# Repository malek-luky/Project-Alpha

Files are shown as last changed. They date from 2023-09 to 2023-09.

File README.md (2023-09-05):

# Project Alpha - THRUST VECTOR CONTROLLED ROCKET MODEL
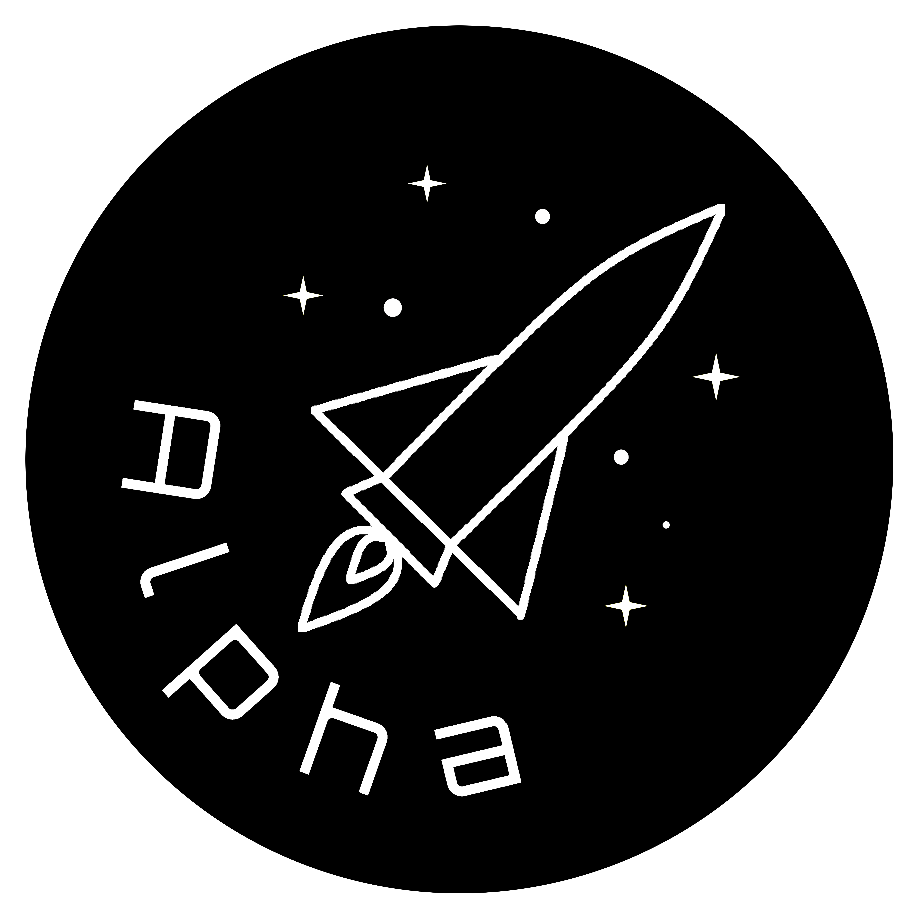
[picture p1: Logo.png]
Project Alpha Logo


## Table of Contents
- [Introduction](#introduction)
- [Material](#material)
- [3D Model](#3d-model)
- [Flight Software](#flight-software)
- [Disclaimer](#disclaimer)

## Introduction
Welcome to the repository for Project Alpha, a bachelor thesis project conducted at the Czech Technical University in Prague. This project focuses on the development and implementation of a thrust vector controlled rocket model. This README.md provides an overview of the project, its materials, and a brief disclaimer regarding the use of the flight software.

## Material
### Flight Computer
- **Barometer**: BMP388
- **Orientation Sensor**: BNO055
- **Microcontroller**: Teensy 4.1

### Additional Hardware
- **Servo Motor**: SG92R
- **Rocket Motor**: Klima D3-P

## 3D Model
The 3D model files included in this repository are essential for printing the rocket. These files come in both STL and Autodesk Inventor formats, providing flexibility for users. The rocket model was specifically designed to accommodate a custom PCB and has been printed using ASA material.

## Flight Software
**Important:** The flight software provided in this repository is experimental and should be used at your own risk. It is intended to serve as a reference and a starting point for your own projects or research related to thrust vector controlled rocketry. Make sure to thoroughly test and validate any modifications you make to the software before using it for an actual rocket launch.

The flight software includes code for controlling the rocket's flight based on data from the sensors and the servo motor. It is designed to assist in achieving thrust vector control, a critical aspect of rocket stability during flight.

## Disclaimer
Launching the rocket based on the mentioned steps and utilizing the flight software is entirely at your own risk. This repository is meant to provide inspiration and study material for educational purposes and research. It is not intended as a comprehensive guide or a guarantee of a fully working prototype.

Safety is paramount when dealing with rocketry, and it is essential to adhere to all safety regulations and guidelines established by your local authorities. Always conduct thorough testing and follow best practices to ensure the safety of yourself and others involved in the project.

If you have any questions or need further information about Project Alpha, feel free to reach out to the project contributors listed in the repository. Good luck with your research and exploration in the field of thrust vector controlled rocketry!

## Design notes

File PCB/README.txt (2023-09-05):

How to use：
1) Open EesyEDA
2) Create new Project
3) Import schematics json (Top menu - File - Open - EasyEDA)
4) Import PCB json

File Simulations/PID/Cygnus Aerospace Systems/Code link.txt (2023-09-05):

https://codesandbox.io/s/rocket-sim-final-with-position-control-dual-motor-0oq6u

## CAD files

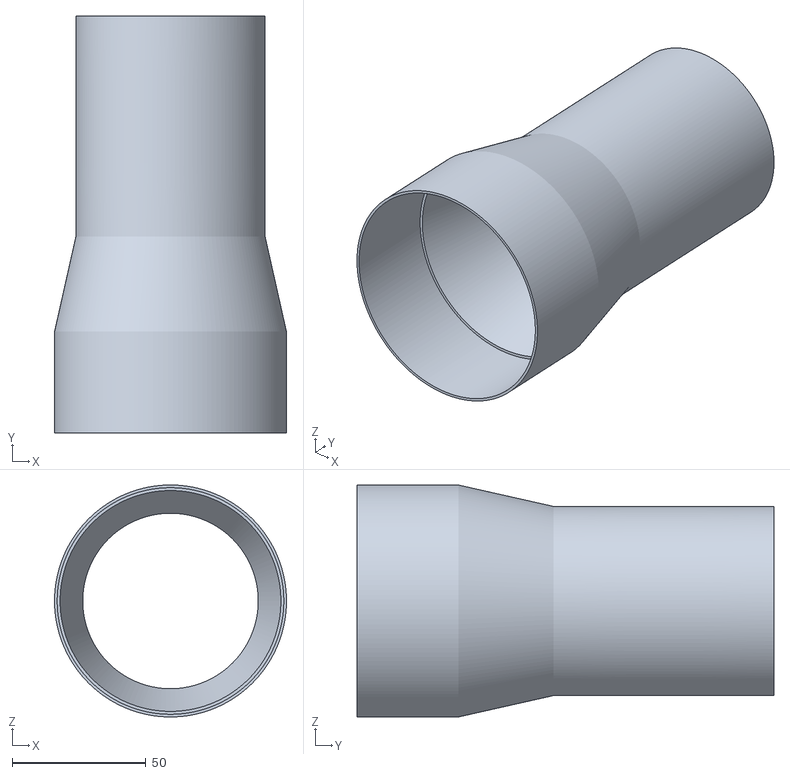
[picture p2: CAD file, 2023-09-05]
3D Models/BottomTubeUp_v7.stl
86.6 x 155.6 x 86.6

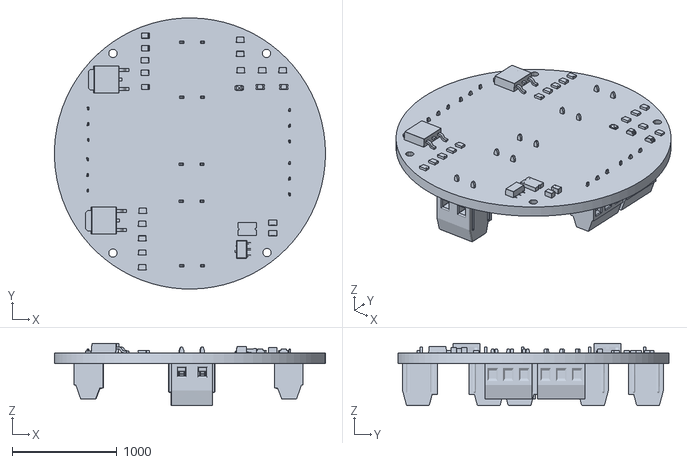
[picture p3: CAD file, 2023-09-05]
3D Models/PCB.stl
2585.4 x 2585.9 x 592.1

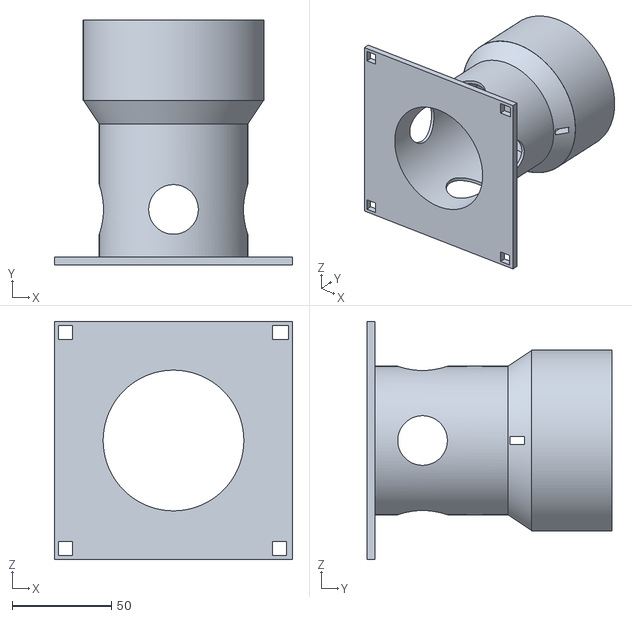
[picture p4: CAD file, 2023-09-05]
3D Models/Stand_v7.stl
120.0 x 123.5 x 120.0

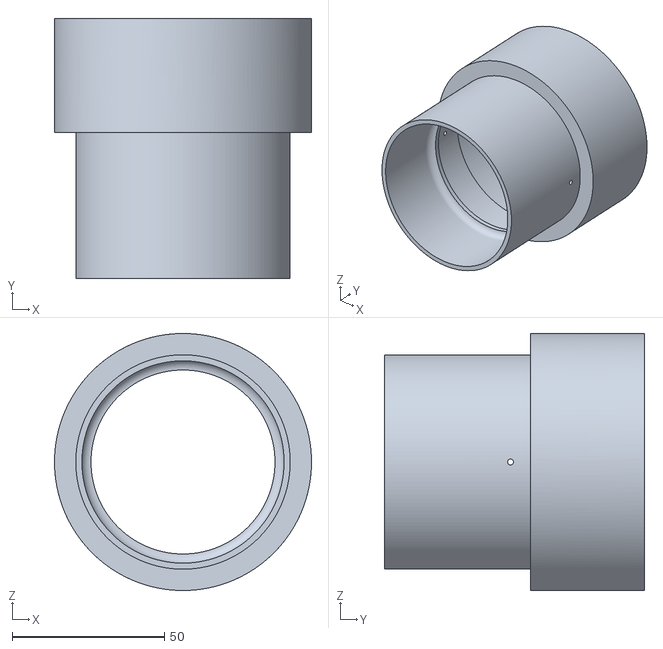
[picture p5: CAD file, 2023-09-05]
3D Models/BottomTubeDown_v7.stl
84.4 x 85.4 x 84.4

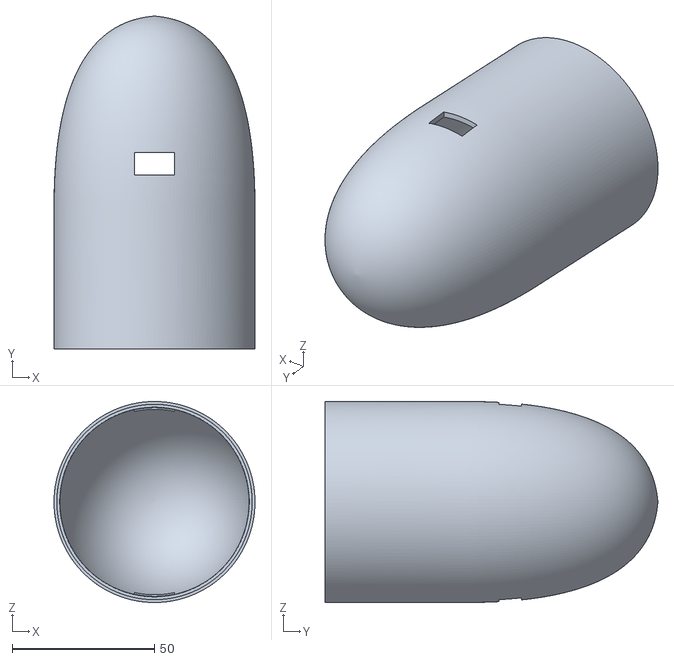
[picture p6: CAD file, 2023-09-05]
3D Models/Cone_v7.stl
70.6 x 116.9 x 70.6

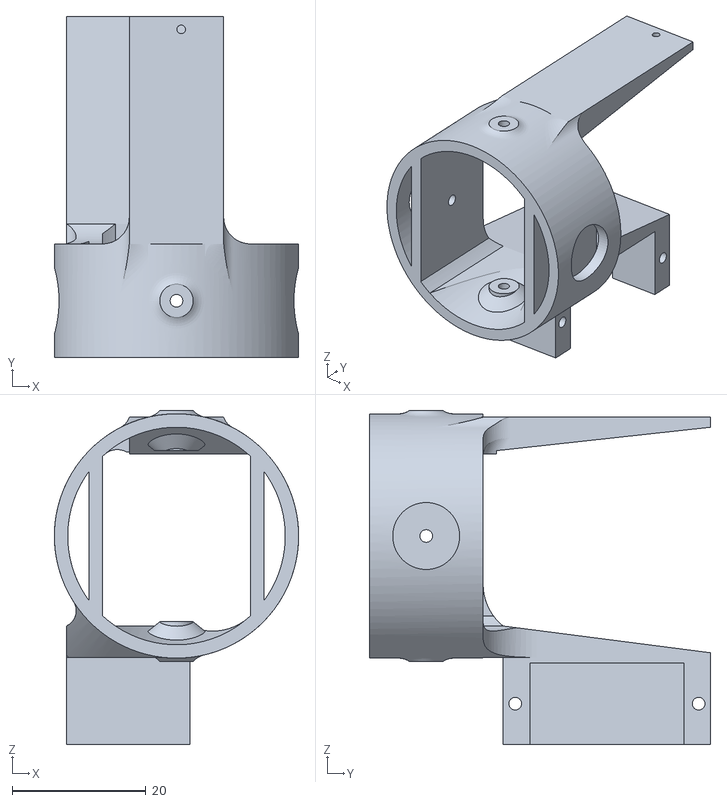
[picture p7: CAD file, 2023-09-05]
3D Models/TVC_v8_inner_stl.stl
36.5 x 51.0 x 49.9

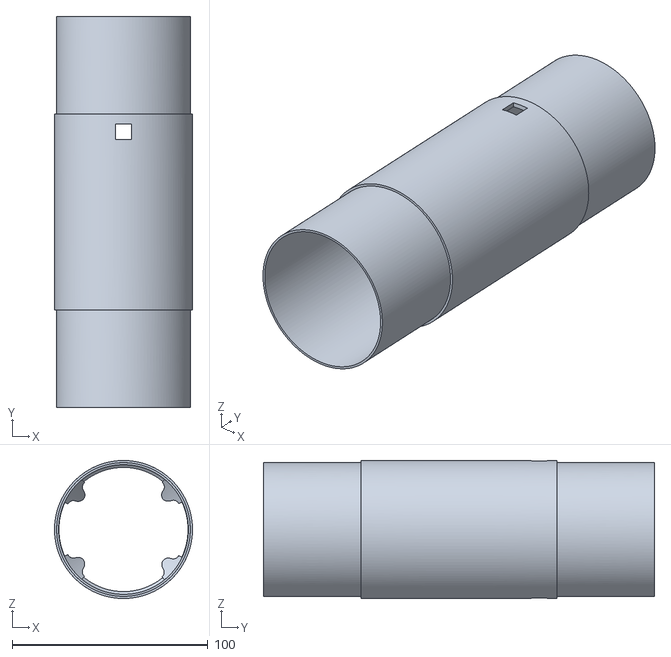
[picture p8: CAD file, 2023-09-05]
3D Models/UpperTube_v7.stl
70.6 x 200.0 x 70.6

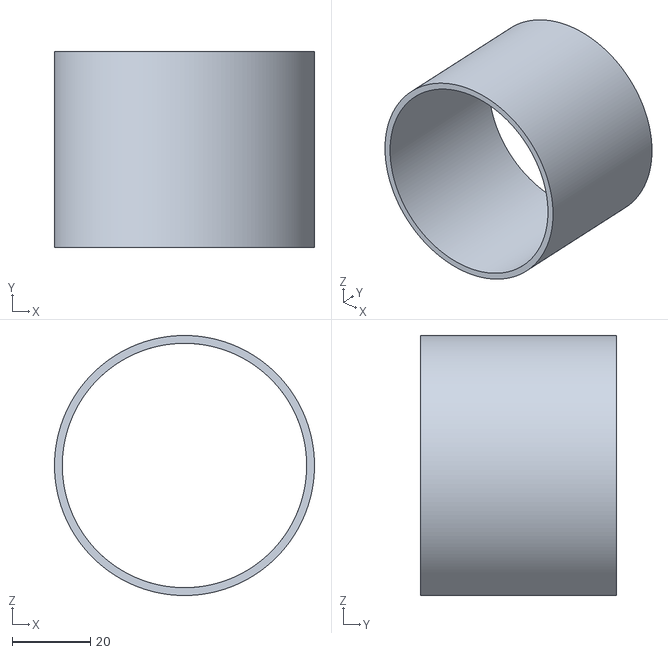
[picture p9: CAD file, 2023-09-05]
3D Models/Extender_v7.stl
66.3 x 50.0 x 66.3

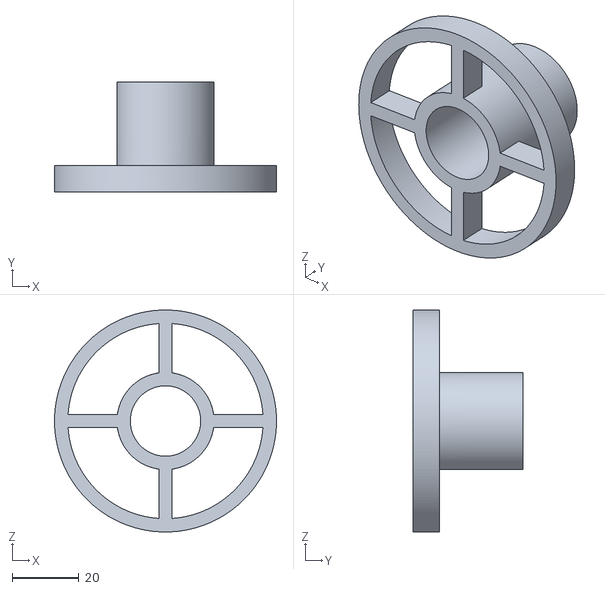
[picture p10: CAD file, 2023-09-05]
3D Models/Calibrator_v7.stl
66.3 x 33.0 x 66.3

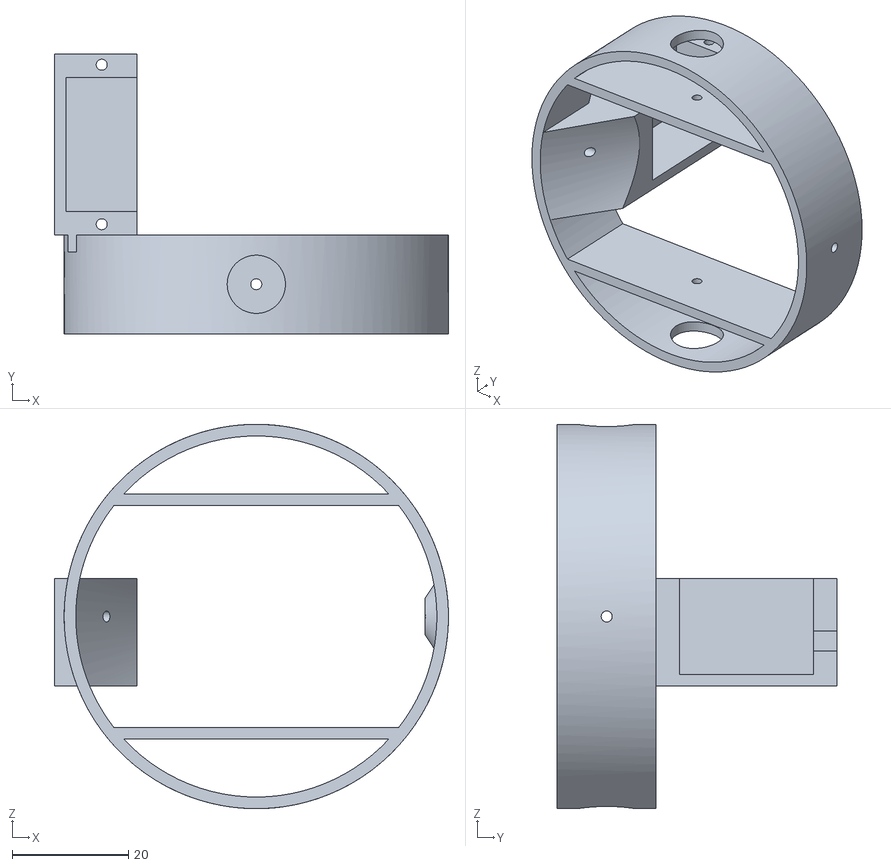
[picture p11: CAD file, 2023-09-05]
3D Models/TVC_v8_outer_stl.stl
67.7 x 48.0 x 66.0

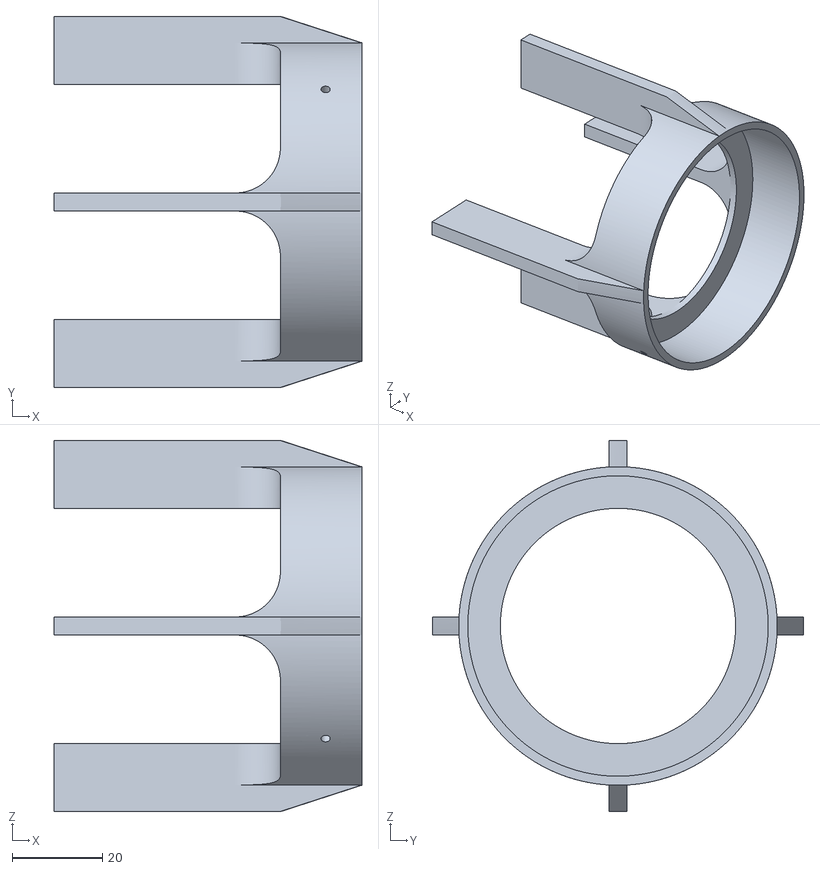
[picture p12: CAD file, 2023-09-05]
3D Models/MountHolder_v7.stl
68.0 x 82.0 x 82.0

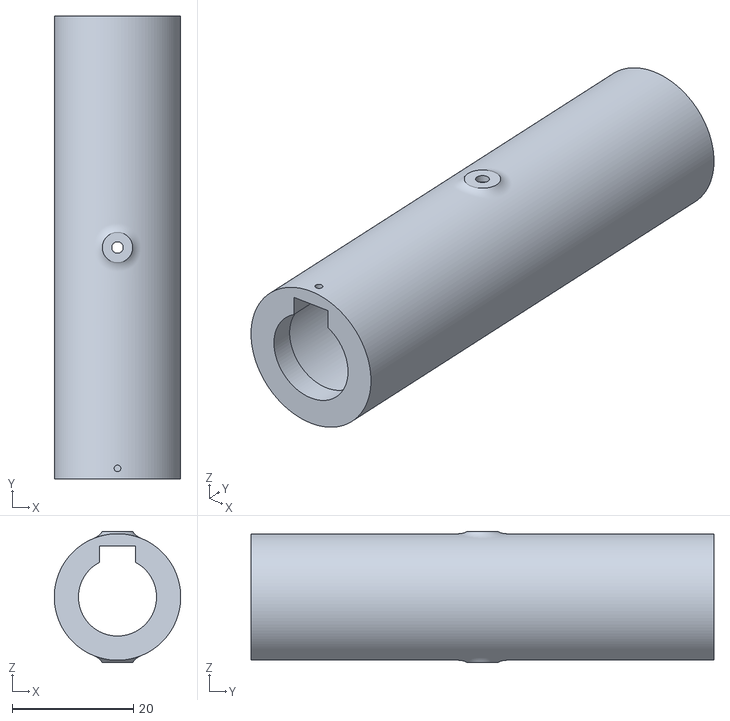
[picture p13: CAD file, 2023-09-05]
3D Models/MotorTube_v7.stl
20.9 x 76.5 x 21.7

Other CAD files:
3D Models/MidTube_v7.stl
3D Models/Autodesk Inventor/BottomTubeDown_v7.ipt
3D Models/Autodesk Inventor/BottomTubeUp_v7.ipt
3D Models/Autodesk Inventor/Calibrator_v7.ipt
3D Models/Autodesk Inventor/Cone_v7.ipt
3D Models/Autodesk Inventor/Extender_v7.ipt
3D Models/Autodesk Inventor/MidTube_v7.ipt
3D Models/Autodesk Inventor/MotorTube_v7.ipt
3D Models/Autodesk Inventor/MountHolder_v7.ipt
3D Models/Autodesk Inventor/Stand_v7.ipt
3D Models/Autodesk Inventor/TVC_v8.ipt
3D Models/Autodesk Inventor/UpperTube_v7.ipt

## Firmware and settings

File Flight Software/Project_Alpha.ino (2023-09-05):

#include <SD.h>
#include <Servo.h> 
#include <Adafruit_BNO055.h>
#include <Adafruit_BMP3XX.h>
#include <Wire.h>
#include <Adafruit_Sensor.h>
#include <utility/imumaths.h>
#define LOG_FILE "data.csv"
#define LED_PIN 13

//BMP
#define BMP_SCK 13
#define BMP_MISO 12
#define BMP_MOSI 11
#define BMP_CS 10
#define SEALEVELPRESSURE_HPA (1013.25)

////////////////////////////////////
// SETUP ELECTRONICS COMPONENTS
////////////////////////////////////

Adafruit_BNO055 bno = Adafruit_BNO055(55, 0x28, &Wire);
Adafruit_BMP3XX bmp; // Initialize BMP388 sensor
const int chipSelect = BUILTIN_SDCARD;
File logFile;
Servo ServoX;
Servo ServoY;

////////////////////////////////////
// CHANGE VARIABLES HERE
////////////////////////////////////
double xCenter = 73;
double yCenter = 91;
double maxAngle = 8;
double weird_offsetX = 1.5;
double weird_offsetY = 1.4;
double x_origin = 0;//calibrated values
double y_origin = 0;//calibrated values
double pX[] = {0.0002, 0.0108, 1.6939, -0.0027};
double pY[] = { 0.0012, 0.0189, 2.3005, -0.0136};

////////////////////////////////////
// CHANGE PID HERE
////////////////////////////////////
double Kp = 0.20825;
double Ki = 0.32;
double Kd = 0.06;

////////////////////////////////////
// DECLARE ALL VARIABLES
////////////////////////////////////
double errorX, errorY;
double proportionalX = 0, proportionalY = 0;
double integralX = 0, integralY = 0;
double derivativeX = 0, derivativeY = 0;
double prev_errorX = 0, prev_errorY = 0;
double OutputX = 0, OutputY = 0;
double MotorAngleX = 0, MotorAngleY = 0;
double x = 0, y=0;
double liftoff,streak,prev_liftoff = 0;
double xAngle=90, yAngle=0;
bool start = false;
bool launch = false;
bool skip_calib = false;
double currentTime = micros();
double cycleTime = micros();
double flightTime = 0;
double dt = 0;
double launchTime = 0;

////////////////////////////////////
// SETUP
////////////////////////////////////

void setup()
{
  // Welcome message
  Serial.begin(115200);
  Serial.println("TVC Alpha Flight Computer"); Serial.println("");

  // Turn on the LED
  pinMode(LED_PIN, OUTPUT);
  digitalWrite(LED_PIN, HIGH);

  // Attach Teensy pins
  ServoX.attach(15);
  ServoY.attach(14);


  // Initialize SD card
  if (!SD.begin(chipSelect))
  {
    Serial.println("Failed to initialize SD card!");
    while (1);
  }

  // Open the log file
  SD.remove(LOG_FILE);
  logFile = SD.open(LOG_FILE, FILE_WRITE);
  if (!logFile)
  {
    Serial.println("Failed to open log file!");
    while (1);
  }

  //Print PIDF values
  Serial.println(Kp,4);
  Serial.println(Ki,4);
  Serial.println(Kd,4);
  logFile.println(Kp,4);
  logFile.println(Ki,4);
  logFile.println(Kd,4);

  // Write the header line to the log file 
  logFile.println("state,currentTime,x,y,liftoff,acc,errorX,errorY,proportionalX,proportionalY,integralX,integralY,derivativeX,derivativeY,MotorAngleX,MotorAngleY,OutputX,OutputY,prev_errorX,prev_errorY,flightTime,dt,x_origin,y_origin, pressure");

  // Initialise the sensor
  if(!bno.begin())
  {
    Serial.print("Ooops, no BNO055 detected ... Check your &Wire or I2C ADDR!");
    while(1);
  }
  bno.setExtCrystalUse(true); //enables external crystal for clock

  // Check BMP
  if (!bmp.begin_I2C(BMP3XX_DEFAULT_ADDRESS, &Wire1)) {   // hardware I2C mode, can pass in address & alt Wire
    Serial.println("Could not find a valid BMP3 sensor, check wiring!");
    while (1);
  }
  bmp.setTemperatureOversampling(BMP3_OVERSAMPLING_8X); // Set temperature oversampling
  bmp.setPressureOversampling(BMP3_OVERSAMPLING_4X); // Set pressure oversampling
  bmp.setIIRFilterCoeff(BMP3_IIR_FILTER_COEFF_3); // Set IIR filter coefficient
  bmp.setOutputDataRate(BMP3_ODR_50_HZ); // Set output data rate

  // Go to center and wait
  ServoX.write(xCenter);
  ServoY.write(yCenter);
  delay(2000);
  currentTime = micros();
}

void loop()
{  
  // Get the time difference
  dt = (micros()-cycleTime)/1000000;

  // Update current time
  currentTime = micros();
  
  // Get a new sensor event
  sensors_event_t orientationData , accelerometerData;
  uint8_t system, gyro, accel, mag = 0;
  bno.getCalibration(&system, &gyro, &accel, &mag);
  
  bno.getEvent(&accelerometerData, Adafruit_BNO055::VECTOR_ACCELEROMETER);
  bno.getEvent(&orientationData, Adafruit_BNO055::VECTOR_EULER);
  x = -orientationData.orientation.y - x_origin; //x = y
  y = orientationData.orientation.z - y_origin; //y = -z
  prev_liftoff = liftoff;
  liftoff = accelerometerData.acceleration.z;
  // Check calibration
//  while (system!=3 or accel!=3)
//  {
//    if (system == 3 and accel ==3)
//    {
//      digitalWrite(LED_PIN, LOW);
//      break;
//    }
//    delay(1000);
//    Serial.println("Calibrate sensor!");
//  }
  
  // BMP
  if (! bmp.performReading()) {
    Serial.println("Failed to perform reading :(");
  }

  
  ////////////////////////////////////////
  // CHECK BNO INIT
  ////////////////////////////////////////
  if (x==0 and y==0 and liftoff==0)
  {
    while(1);
  }

  ////////////////////////////////////////
  // CALIBRATION
  ////////////////////////////////////////
  skip_calib=false;
  if (skip_calib==true)
  {
    start = true;
  }
  if (start==false and skip_calib==false)
  {
    // Write the new values
    start = true;
    delay(3000);
    
    for (int i = 0; i < 4000; i++) {
      // Calculate new X and Y angles
      xAngle += 0.01;
      
      // Calculate new X and Y positions
      double MotorAngleX = maxAngle*sin(xAngle);

      // Transfer angle to readl position
      OutputX = weird_offsetX * (pX[0] * pow(MotorAngleX, 3) + pX[1] * pow(MotorAngleX, 2) + pX[2] * MotorAngleX + pX[3]);
      
      // Add the centre values
      OutputX = OutputX+xCenter;
      
      // Move servos to new X and Y positions
      Serial.print("OutputX: ");
      Serial.println(OutputX-xCenter,4);
      Serial.print("MotorAngleX: ");
      Serial.println(MotorAngleX,4);
      ServoX.write(OutputX);
      
      // Wait for servos to reach new positions
      delay(2);
    }

    // Center postiion
    ServoX.write(xCenter);
    ServoY.write(yCenter);
    delay(2000);
    
    for (int i = 0; i < 4000; i++) {
      // Calculate new X and Y angles
      yAngle += 0.01;
      
      // Calculate new X and Y positions
      double MotorAngleY = maxAngle*sin(yAngle);

      // Transfer angle to readl position
      OutputY = weird_offsetY * (pY[0] * pow(MotorAngleY, 3) + pY[1] * pow(MotorAngleY, 2) + pY[2] * MotorAngleY + pY[3]);
      
      // Add the centre values
      OutputY = OutputY+yCenter;
      
      // Move servos to new X and Y positions
      ServoY.write(OutputY);
      
      // Wait for servos to reach new positions
      delay(2);
    }

    // Update new x and y values
    sensors_event_t event;
    bno.getEvent(&event);    
    x = event.orientation.y - x_origin; //x = y
    y = -event.orientation.z - y_origin; //y = -z
  
    // Center postiion
    ServoX.write(xCenter);
    ServoY.write(yCenter);
    delay(3000);
  }

  ////////////////////////////////////////
  // LIFTOFF DETECTION
  ////////////////////////////////////////
  if (abs(liftoff-prev_liftoff)>1.5 and start==true and launch ==false)
  {
    streak=streak+1;
    if (streak>1)
    {
    launchTime = micros();
    launch = true;
    Serial.print("Liftoff: ");
    Serial.println(launchTime);
    logFile.print("Liftoff: ");
    logFile.println(launchTime);
    //0.615s liftoff
    //1.2s Back to 3N
    //=0.585s after liftoff
    }
  }
  else
  {
    streak = 0;
  }
  if (launch==true)
  {
    flightTime = (currentTime-launchTime)/1000000;
  }

  ////////////////////////////////////////
  // STATE LOG
  ////////////////////////////////////////
  // Frequency 50Hz - dt>0.019
  // Start after the first thrust peak: launch==true and (currentTime-laumchTime)/1000000>0.585
  // In first 3s the reading is corrupted influencing Integrative term
  
  if (dt>0.019)
  {
  if (launch==true and currentTime>3000000)
  {    
    Serial.print("State: ");
    Serial.print("Liftoff, ");
    logFile.print("Liftoff, ");

    // Update time
    cycleTime = micros();

    ////////////////////////////////////////
    // PID
    ////////////////////////////////////////
    // Get the errors
    errorX = x;
    errorY = y;

    // Compute Proportional
    proportionalX = errorX*Kp;
    proportionalY = errorY*Kp;

    // Compute integral
    integralX += (errorX * dt)*Ki;
    integralY += (errorY * dt)*Ki;

    // Prevent Wind-up
    integralX = constrain(integralX, -maxAngle, +maxAngle);
    integralY = constrain(integralY, -maxAngle, +maxAngle);

    // Compute derivative
    derivativeX = Kd * (errorX - prev_errorX) / dt;
    derivativeY = Kd * (errorY - prev_errorY) / dt;

    // Compute output using PID formula
    MotorAngleX = proportionalX + integralX + derivativeX;
    MotorAngleY = proportionalY + integralY + derivativeY;

    // Limit motor angle range
    MotorAngleX = constrain(MotorAngleX, -maxAngle, maxAngle);
    MotorAngleY = -constrain(MotorAngleY, -maxAngle, maxAngle);
    
    // Transfer motor angle to servo values
    OutputX = weird_offsetX * (pX[0] * pow(MotorAngleX, 3) + pX[1] * pow(MotorAngleX, 2) + pX[2] * MotorAngleX + pX[3]);
    OutputY = weird_offsetY * (pY[0] * pow(MotorAngleY, 3) + pY[1] * pow(MotorAngleY, 2) + pY[2] * MotorAngleY + pY[3]);

    // Add the centre values
    OutputX = OutputX+xCenter;
    OutputY = OutputY+yCenter;

    // Update servo positions
    ServoX.write(OutputX);
    ServoY.write(OutputY);
    
    // Update previous error
    prev_errorX = errorX;
    prev_errorY = errorY;
  }

  else
  {
    Serial.print("State: ");
    Serial.print("Ground, ");
    logFile.print("Ground, ");

    // Update time
    cycleTime = micros();
  }

  ////////////////////////////////////////
  // DATA LOG
  ////////////////////////////////////////
  // Display the doubleing point data
  Serial.print("currentTime: ");
  Serial.print(currentTime);
  Serial.print(", x: ");
  Serial.print(x, 4);
  Serial.print(", y: ");
  Serial.print(y, 4);
  Serial.print(", liftoff: ");
  Serial.print(liftoff-prev_liftoff, 4);
  Serial.print(", acc: ");
  Serial.print(liftoff, 4);
  Serial.print(", ErrorX: ");
  Serial.print(errorX, 4);
  Serial.print(", ErrorY: ");
  Serial.print(errorY, 4);
  Serial.print(", proportionalX: ");
  Serial.print(proportionalX, 4);
  Serial.print(", proportionalY: ");
  Serial.print(proportionalY, 4);
  Serial.print(", integralX: ");
  Serial.print(integralX, 4);
  Serial.print(", integralY: ");
  Serial.print(integralY, 4);
  Serial.print(", derivativeX: ");
  Serial.print(derivativeX, 4);
  Serial.print(", derivativeY: ");
  Serial.print(derivativeY, 4);
  Serial.print(", MotorAngleX: ");
  Serial.print(MotorAngleX, 4);
  Serial.print(", MotorAngleY: ");
  Serial.print(MotorAngleY, 4);
  Serial.print(", OutputX: ");
  Serial.print(OutputX, 4);
  Serial.print(", OutputY: ");
  Serial.print(OutputY, 4);
  Serial.print(", flightTime: ");
  Serial.print(flightTime,4);
  Serial.print(", dt: ");
  Serial.print(dt,4);
  Serial.print(", Pressure: ");
  Serial.print(bmp.pressure,4);
  Serial.println();

  // Write the data to the log file
  logFile.print(currentTime);
  logFile.print(",");
  logFile.print(x, 4);
  logFile.print(",");
  logFile.print(y, 4);
  logFile.print(",");
  logFile.print(liftoff-prev_liftoff, 4);
  logFile.print(",");
  logFile.print(liftoff, 4);
  logFile.print(",");
  logFile.print(errorX, 4);
  logFile.print(",");
  logFile.print(errorY, 4);
  logFile.print(",");
  logFile.print(proportionalX, 4);
  logFile.print(",");
  logFile.print(proportionalY, 4);
  logFile.print(",");
  logFile.print(integralX, 4);
  logFile.print(",");
  logFile.print(integralY, 4);
  logFile.print(",");
  logFile.print(derivativeX, 4);
  logFile.print(",");
  logFile.print(derivativeY, 4);
  logFile.print(",");
  logFile.print(MotorAngleX, 4);
  logFile.print(",");
  logFile.print(MotorAngleY, 4);
  logFile.print(",");
  logFile.print(OutputX, 4);
  logFile.print(",");
  logFile.print(OutputY, 4);
  logFile.print(",");
  logFile.print(prev_errorX, 4);
  logFile.print(",");
  logFile.print(prev_errorY, 4);
  logFile.print(",");
  logFile.print(flightTime, 4);
  logFile.print(",");
  logFile.print(dt, 4);
  logFile.print(",");
  logFile.print(x_origin, 4);
  logFile.print(",");
  logFile.print(y_origin, 4);
  logFile.print(",");
  logFile.print(bmp.pressure,4);
  logFile.println();

  // Flush SD CArd
  logFile.flush();
  }
}
